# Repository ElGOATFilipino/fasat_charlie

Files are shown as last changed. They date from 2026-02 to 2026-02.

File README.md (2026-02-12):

# FASat_charlie macropad
This is a macropad in the shape of the chilean satelite FASat-CHARLIE. It has 6 keys with a rotary encoder, 16 SK6812MINI-E leds on the edges of its pcb and uses kmk firmware.

I made this macropad to help me open the websites I need for school instantly, to record as well as mute! (Since I costantly forget the keybinds for those).

## Features: 
- 16 SK6812MINI-E leds, all used for as a "glow" that the macropad emanates in the dark!
- EC11 Rotary encoder /w switch for adjusting led colors and brightness
- 6 keys
- Shape of the FASat-CHARLIE satelite

## CAD
The entire case uses 6 M3x16mm bolts and M3 headseat inserts (4mm deep). 4 are screwed from under the case and the other 2 are used to join the "flag".

The case has 3 separate 3d printed pieces. The bottom, which has a 16 degree inclination so it can face me once I lay it flat on a surface. It also has info. about the satelite on the back. 
The top exposes the pcb so the leds can be seen and has a circular hole where the buttons and rotary encoder will be. 
Lastly, the flag is just a decorative piece that contains acknowlegements.

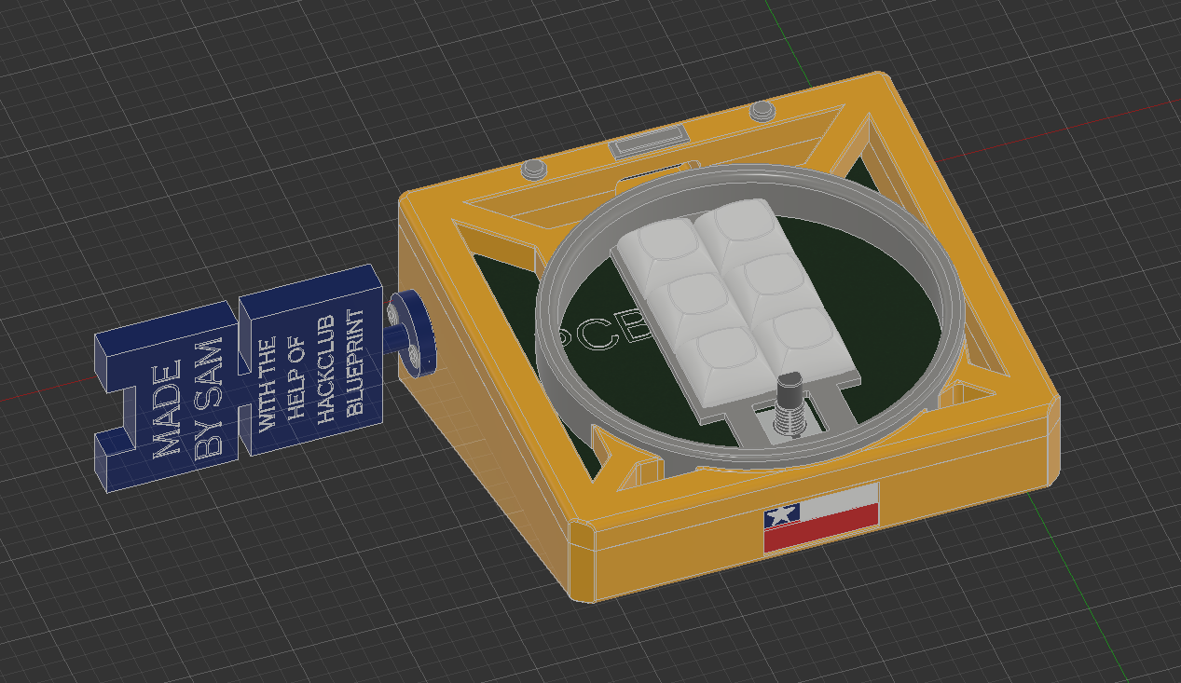
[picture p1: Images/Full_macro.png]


Here's how it'll all fit together

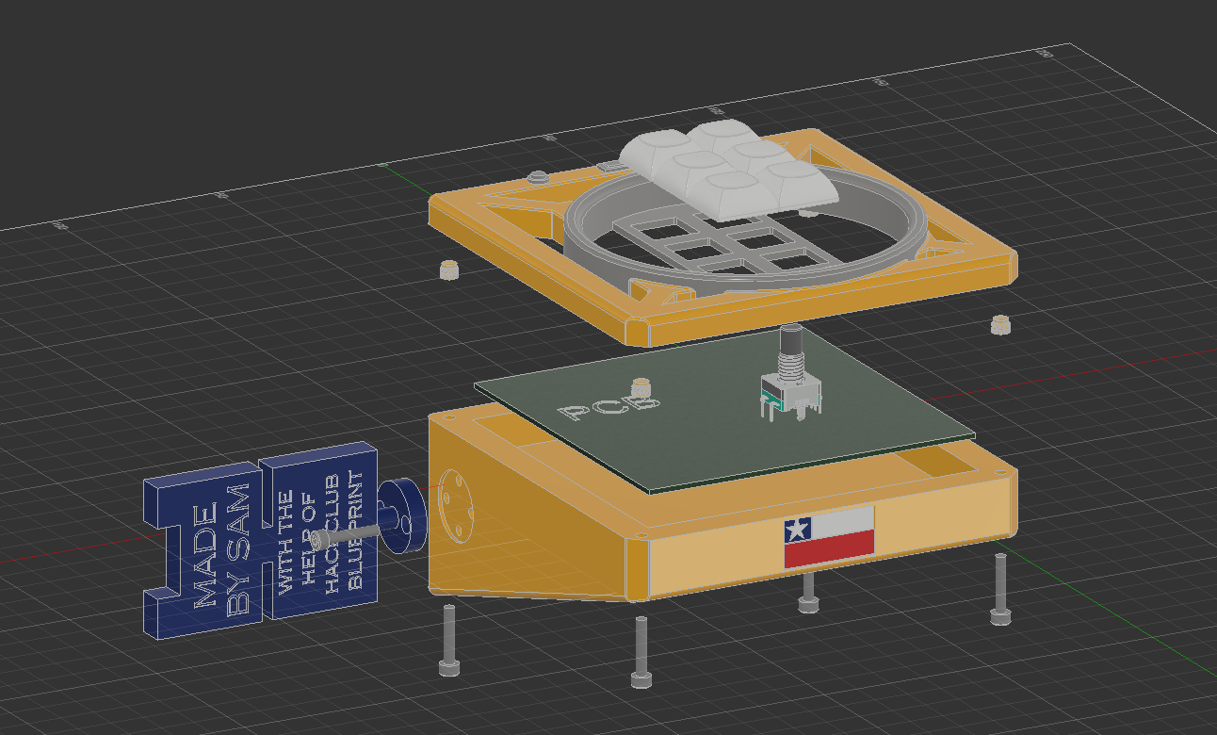
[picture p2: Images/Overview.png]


*All made in Fusion 360, the model is too big so I had to compress it into a zip file.

## PCB
The pcb was made in KiCAD! I had a lot of fun using this software for my pcb, I think i'll be using it for future projects!

Schematic
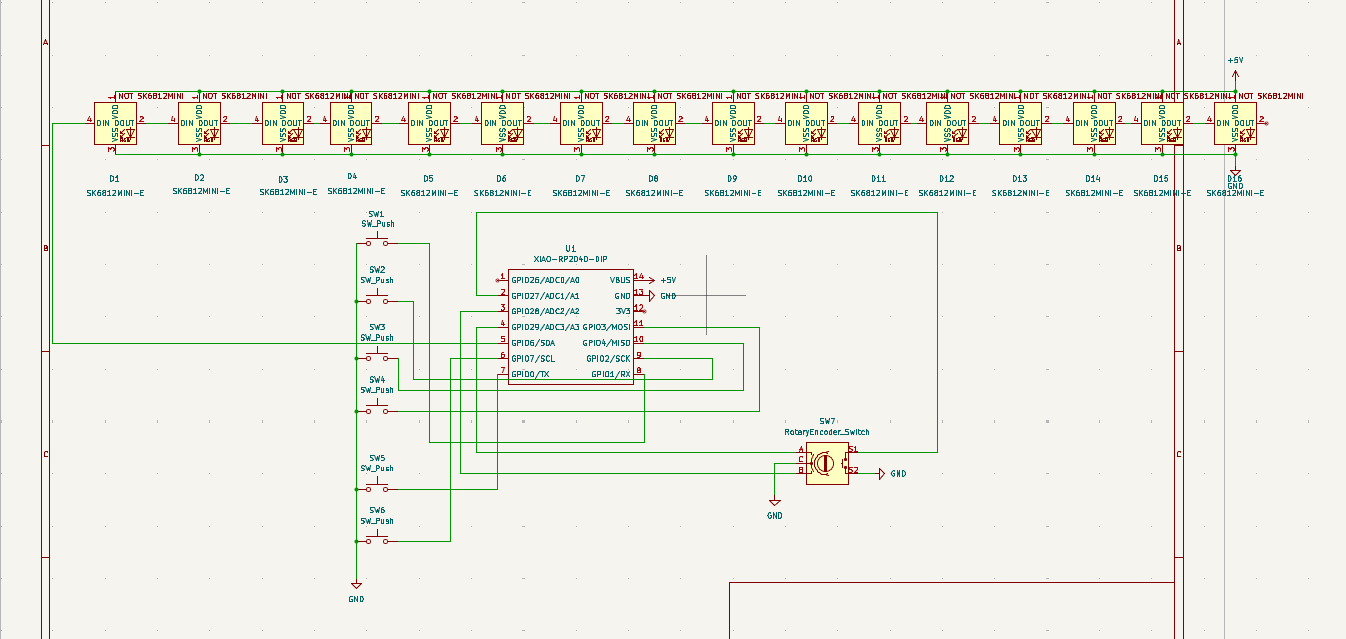
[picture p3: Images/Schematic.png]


PCB (It contains a lot of errors, since the DRC thinks that the edge.cuts on the leds is not supposed to be there, but it is).
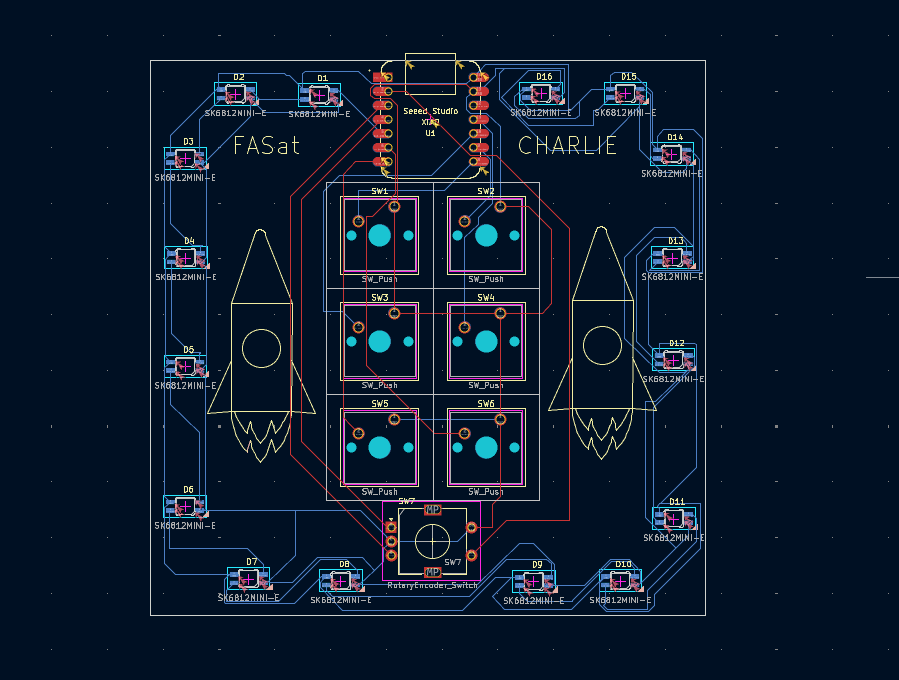
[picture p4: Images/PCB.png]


## Firmware features (not required, but still good to add!)
- Rotary encoder can adjust the brightness of leds. If the button is pressed it turn the leds red, orange, yellow, green, blue, purple, make them do a rainbow animation and finally, off. (Example: if I press the button 4 times, the leds turn green.)
- Four of the keys open Turbo.ai, Canva, Word, Google classroom. The other two start recording on my computer and mute volume.

## BOM
Here are all the parts needed to make my macropad!

- x6 MX-Style switches (Cherry)
- x6 DSA keycaps (1u)
- x6 M3x16mm SHCS bolts
- x4 M3x5x4 headseat inserts
- x16 SK6812MINI-E LEDs
- x1 EC11 Rotary Encoder
- x1 XIAO RP2040-DIP
- x1 Case (3 3d printed parts)

## Fun facts:
- It was supposed to be in the shape of the sojourner rover (which took me 2 weeks to complete), but it was to big and ugly.
- I was inspired to make it in the shape of the FASat-CHARLIE when I saw a replica of it at Santiago's National Museum of Aeronautics and space.

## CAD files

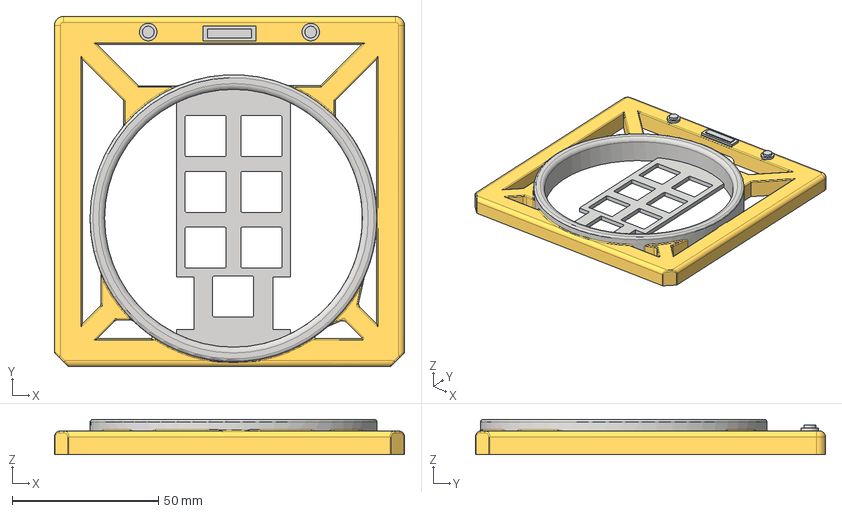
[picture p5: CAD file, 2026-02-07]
production/TOP.step
119.5 x 119.5 x 12.1 mm

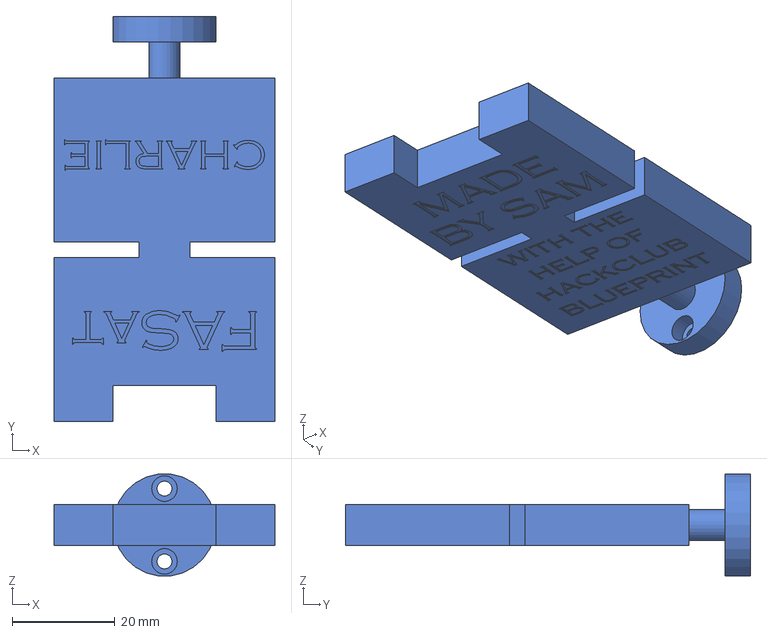
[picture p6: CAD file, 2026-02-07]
production/Flag.step
43.1 x 79.0 x 19.9 mm

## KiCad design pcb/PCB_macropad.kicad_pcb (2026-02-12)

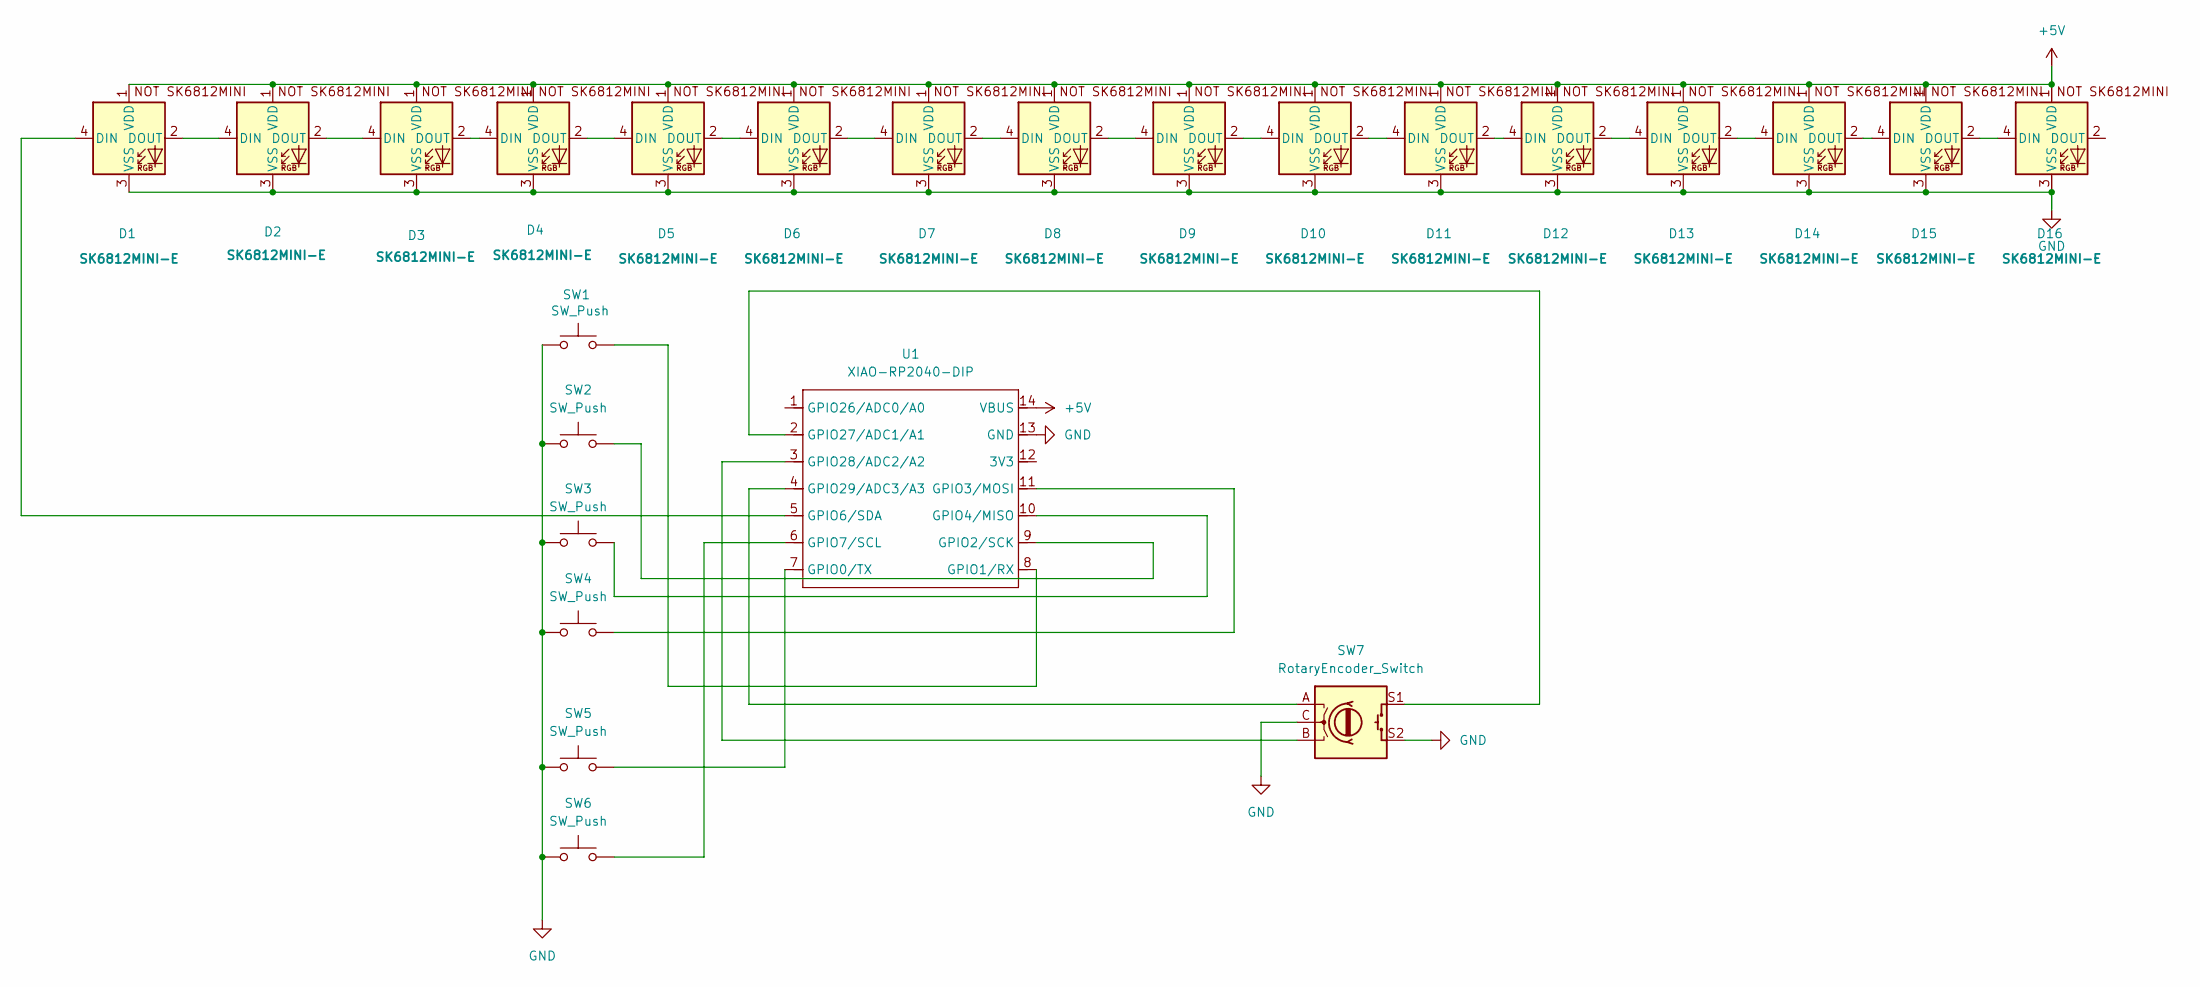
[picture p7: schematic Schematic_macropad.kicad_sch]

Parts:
D1, D2, D3, D4, D5, D6, D7, D8, D9, D10, D11, D12, D13, D14, D15, D16: SK6812MINI-E; SK6812MINI-E_fixed
SW1, SW2, SW3, SW4, SW5, SW6: SW_Push; SW_Cherry_MX_1.00u_PCB
SW7: RotaryEncoder_Switch; RotaryEncoder_Alps_EC11E-Switch_Vertical_H20mm
U1: XIAO-RP2040-DIP; XIAO-Generic-Hybrid-14P-2.54-21X17.8MM

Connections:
+5V: D1.1 (VDD), D2.1 (VDD), D3.1 (VDD), D4.1 (VDD), D5.1 (VDD), D6.1 (VDD), D7.1 (VDD), D8.1 (VDD), D9.1 (VDD), D10.1 (VDD), D11.1 (VDD), D12.1 (VDD), D13.1 (VDD), D14.1 (VDD), D15.1 (VDD), D16.1 (VDD), U1.14 (VBUS)
GND: D1.3 (VSS), D2.3 (VSS), D3.3 (VSS), D4.3 (VSS), D5.3 (VSS), D6.3 (VSS), D7.3 (VSS), D8.3 (VSS), D9.3 (VSS), D10.3 (VSS), D11.3 (VSS), D12.3 (VSS), D13.3 (VSS), D14.3 (VSS), D15.3 (VSS), D16.3 (VSS), SW1.1, SW2.1, SW3.1, SW4.1, SW5.1, SW6.1, SW7.C, SW7.S2, U1.13 (GND)
unnamed: D1.4 (DIN), U1.5 (GPIO6/SDA)
unnamed: D1.2 (DOUT), D2.4 (DIN)
unnamed: D2.2 (DOUT), D3.4 (DIN)
unnamed: D3.2 (DOUT), D4.4 (DIN)
unnamed: D4.2 (DOUT), D5.4 (DIN)
unnamed: D5.2 (DOUT), D6.4 (DIN)
unnamed: D6.2 (DOUT), D7.4 (DIN)
unnamed: D7.2 (DOUT), D8.4 (DIN)
unnamed: D8.2 (DOUT), D9.4 (DIN)
unnamed: D9.2 (DOUT), D10.4 (DIN)
unnamed: D10.2 (DOUT), D11.4 (DIN)
unnamed: D11.2 (DOUT), D12.4 (DIN)
unnamed: D12.2 (DOUT), D13.4 (DIN)
unnamed: D13.2 (DOUT), D14.4 (DIN)
unnamed: D14.2 (DOUT), D15.4 (DIN)
unnamed: D15.2 (DOUT), D16.4 (DIN)
unnamed: SW5.2, U1.7 (GPIO0/TX)
unnamed: SW1.2, U1.8 (GPIO1/RX)
unnamed: SW2.2, U1.9 (GPIO2/SCK)
unnamed: SW4.2, U1.11 (GPIO3/MOSI)
unnamed: SW3.2, U1.10 (GPIO4/MISO)
unnamed: SW6.2, U1.6 (GPIO7/SCL)
unnamed: SW7.S1, U1.2 (GPIO27/ADC1/A1)
unnamed: SW7.B, U1.3 (GPIO28/ADC2/A2)
unnamed: SW7.A, U1.4 (GPIO29/ADC3/A3)

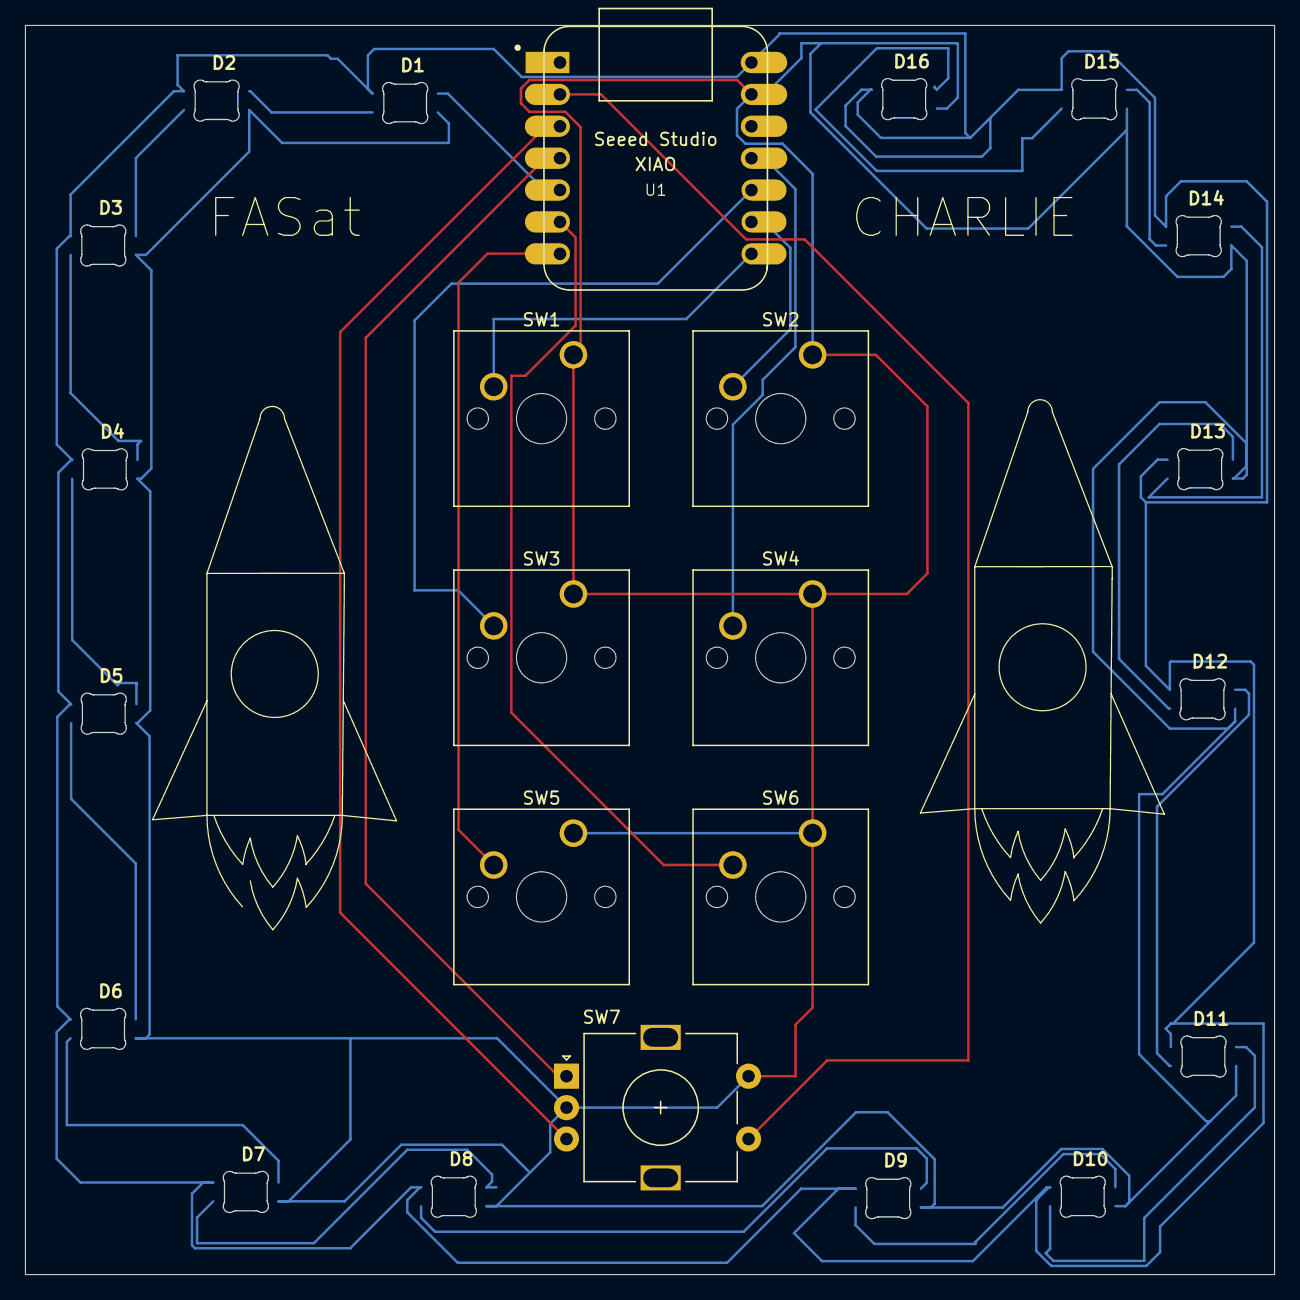
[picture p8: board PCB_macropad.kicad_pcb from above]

Board: 2 copper layers, 99.5 x 99.5 mm, 24 parts (0 on the bottom side), 27 nets.
